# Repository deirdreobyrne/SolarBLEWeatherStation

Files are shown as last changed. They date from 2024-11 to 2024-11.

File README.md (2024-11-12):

# Solar powered BLE weather station

## Introduction

I wanted a weather sensor for the garden, and I wanted to use the [BTHome protocol](https://bthome.io/format/),
so as to make integration with [Home Assistant](https://www.home-assistant.io/) straightforward.

Whenever we create a solar powered project, it is essential to minimise energy consumption of the electronics. This project achieves this by sending only one
BLE advertisement at a time and entering deep sleep immediately upon the broadcast of that advertisment.

## Hardware used

I used a [Seeed Studio XIAO ESP32C3 module](https://www.seeedstudio.com/Seeed-XIAO-ESP32C3-p-5431.html),
an SHT20 temperature and humidity sensor, and I mounted the project on a [perma-proto board](https://www.aliexpress.com/item/4000301371545.html)

The solar power system I used came from [Jasper Sikken's excellent solar power harvester](https://www.tindie.com/products/jaspersikken/solar-harvesting-into-lithium-ion-capacitor/),
which keeps a 250F Lithium-Ion capacitor charged from solar energy, and provides 3.3v for the project.

## Software

I could not get the software to work with Visual Studio Code, so I wrote it using the [Arduino IDE](https://docs.arduino.cc/software/ide/) instead.

The code broadcasts a single BLE advertismenet about once every 10 seconds, and reads the sensors once every 6 broadcasts.

## Housing

I designed a housing for the project in [FreeCAD](https://www.freecad.org/) - the design is in the *Housing.FCStd* file. It is designed to be cable-tied to a
fence, and uses 2 threaded inserts to keep the circuit board in place, and one to keep the two parts of the housing attached.

## Performance

I believe the sensor will work in total darkness for at least 2 solid continuous weeks. So even in dullest darkest Ireland (where I live) I expect this sensor
to work continuously.

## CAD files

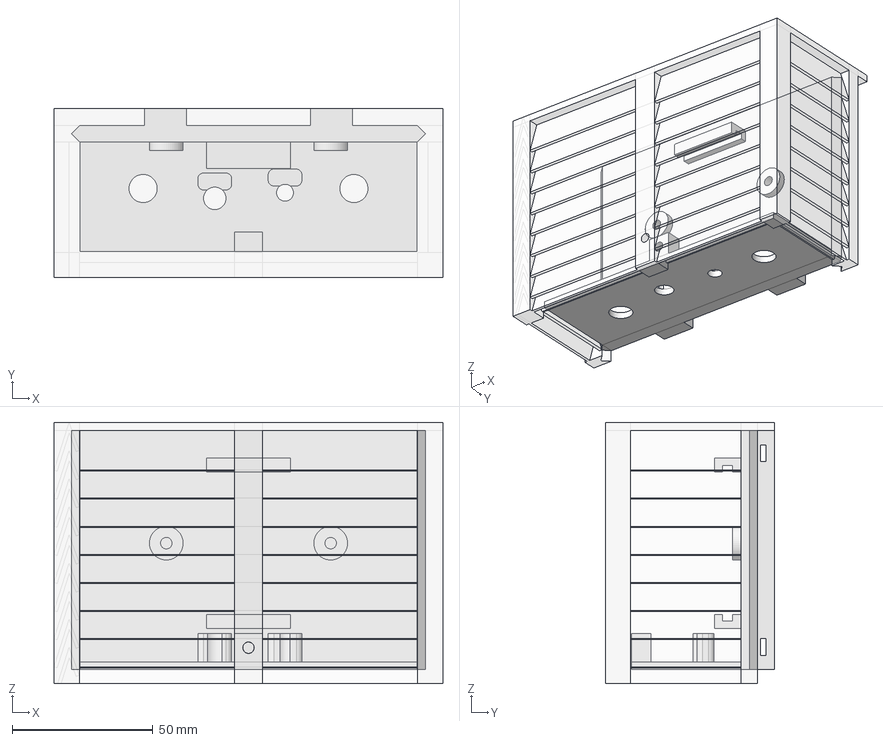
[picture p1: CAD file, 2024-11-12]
Housing.FCStd
138.4 x 60.2 x 93.0 mm

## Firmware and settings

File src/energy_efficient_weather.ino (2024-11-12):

#include <NimBLEDevice.h>
#include <Arduino.h>
#include <Wire.h>
#include <DFRobot_SHT20.h>

// #######################################################
// # XIAO ESP32C3 -- ENSURE THE ESP IS SET FOR 80MHz !!! #
// #######################################################

/* Minimise energy consumption by slowing the CPU to the minimum speed which still supports BLE */
#if F_CPU != 80000000
#  error CPU speed should be set to 80MHz
#endif

#if !CONFIG_BT_NIMBLE_EXT_ADV
#  error Must enable extended advertising, see nimconfig.h file in your Documents -> Arduino -> libraries -> NimBLE-Arduino folder.
#endif

#define MILLIS_TO_MICROS(SEC) SEC ## 000ull
#define SLEEP_DURATION MILLIS_TO_MICROS(9700)
/* We broadcast this number of advertisements before performing another read of the sensors - to save just a little more energy */
#define BROADCASTS_PER_READ 6

NimBLEExtAdvertising *pAdvertising;
volatile bool isAdvertising = true;

RTC_DATA_ATTR float temperature = 0;
RTC_DATA_ATTR float humidity = 0;
RTC_DATA_ATTR uint8_t packetId = 0;
RTC_DATA_ATTR uint8_t broadcastNumber = BROADCASTS_PER_READ;

void performRead() {
  DFRobot_SHT20 sht20;
  broadcastNumber = 0;
  packetId++;
  sht20.initSHT20();
  delay(15);
  temperature=sht20.readTemperature();
  humidity=sht20.readHumidity();
  if (humidity > 99.98) {
	  humidity = 99.98;
  } else if (humidity < 0.02) {
	  humidity = 0.02;
  }
}

class AdvertisingCallbacks: public NimBLEExtAdvertisingCallbacks {
  void onStopped(NimBLEExtAdvertising* pAdv, int reason, uint8_t inst_id) {
    isAdvertising = false;
  }
};

void setup() {
  NimBLEDevice::init("");
  NimBLEExtAdvertisement extAdv(BLE_HCI_LE_PHY_CODED, BLE_HCI_LE_PHY_1M);
  uint8_t packet[25];
  int16_t val;

  if (++broadcastNumber >= BROADCASTS_PER_READ) {
    performRead();
  }

  pAdvertising = NimBLEDevice::getAdvertising();
  pAdvertising->setCallbacks(new AdvertisingCallbacks);
  extAdv.setConnectable(false);
  extAdv.setLegacyAdvertising(true);
  /* BTHome packet - see https://bthome.io/format/ */
  packet[0]=0x02;  // len=2
  packet[1]=0x01;  // flags
  packet[2]=0x06;
  packet[3]=0x08;  // len=8
  packet[4]=0x09;  // name
  packet[5]='W';
  packet[6]='e';
  packet[7]='a';
  packet[8]='t';
  packet[9]='h';
  packet[10]='e';
  packet[11]='r';
  packet[12]=0x0c;  // len=12
  packet[13]=0x16;  // 16-bit uuid
  packet[14]=0xd2;
  packet[15]=0xfc;
  packet[16]=0x40;	// bthome flags
  packet[17]=0x00;	// packet id
  packet[18]=packetId;
  packet[19]=0x02;	// temperature 0.01 C
  val = temperature * 100.0f;
  packet[20]=(val & 0xff);
  packet[21]=((val>>8)&0xff);
  packet[22]=0x03;	// humidity 0.01 pc
  val = humidity*100.0f;
  packet[23]=(val & 0xff);
  packet[24]=((val >> 8)&0xff);
  extAdv.setData(packet,25);
  if (pAdvertising->setInstanceData(0, extAdv)) {
    /* Send only one advertising packet */
    if (pAdvertising->start(0, 0, 1)) {
      do {
        yield();
      /* Exit out of this loop as soon as the packet is sent - saves energy! */
      } while (isAdvertising);
    }
  }
  NimBLEDevice::deinit();
  esp_deep_sleep(SLEEP_DURATION);
}

void loop() {
}
